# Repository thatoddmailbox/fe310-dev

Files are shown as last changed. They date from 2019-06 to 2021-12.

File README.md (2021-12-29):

# fe310-dev

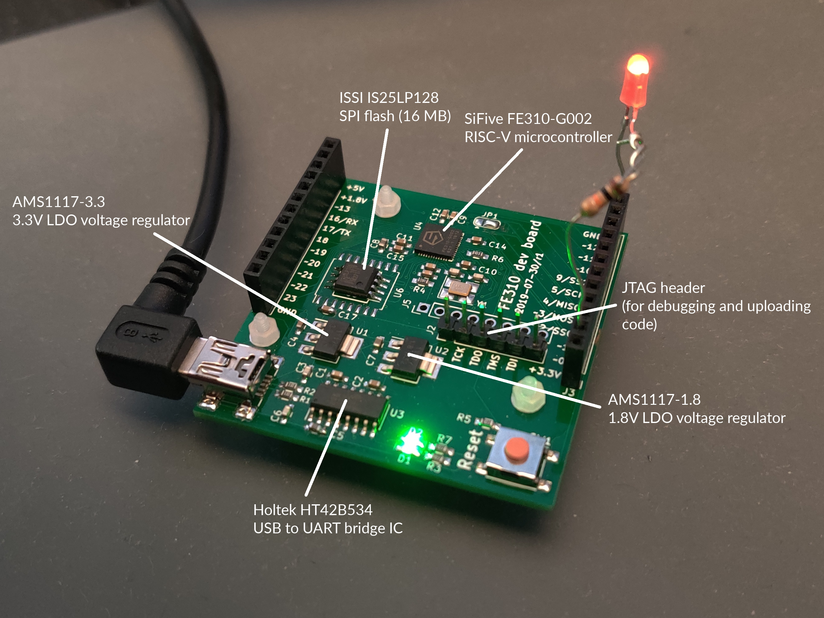
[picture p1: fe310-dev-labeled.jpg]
An image of the board


A development board for the [SiFive FE310](https://sifive.cdn.prismic.io/sifive/4999db8a-432f-45e4-bab2-57007eed0a43_fe310-g002-datasheet-v1p2.pdf), a RISC-V microcontroller. Compatible with both the FE310-G000 and FE310-G002.

## Revisions
* Revision 0 - initial revision
	* [revision 0 schematic](./mfg/rev0/fe310-dev.pdf), [revision 0 gerbers](./mfg/rev0), [revision 0 known issues](https://github.com/thatoddmailbox/fe310-dev/issues?q=is%3Aissue+label%3A%22affects+rev+0%22+) 
* Revision 1 - added support for the G002, added mounting holes, fixed silkscreen labels for pins and LEDs
	* [revision 1 schematic](./mfg/rev1/fe310-dev.pdf), [revision 1 gerbers](./mfg/rev1), [revision 1 known issues](https://github.com/thatoddmailbox/fe310-dev/issues?q=is%3Aissue+label%3A%22affects+rev+1%22+)

## Pinouts
The main pins are on the sides, and are labeled on the silkscreen. PWM capable pins are labeled with a ~, and pins with support for the SPI or UART peripherals have their functions labeled.

In the middle of the board, there are two sets of pins. The first is the JTAG header, which is partially labeled. When holding the board upright (so the "FE310 dev board" text can be read, and the USB port faces upwards), the pins are as follows:

* +3.3V
* TCK
* TDO
* TMS
* TDI
* GND

Most of these should go directly to the matching pin on your JTAG adapter. The one exception is +3.3V. If you want to power the board from your adapter, connect +3.3V to your adapter's power; however, if you want to power the board from USB (so that you can see the serial port), then leave the JTAG header's +3.3V pin disconnected.

The second set of pins has no labels. When holding the board upright, the pins are as follows:

* +1.8V
* AON_PMU_OUT_0
* AON_PMU_OUT_1
* AON_PMU_DWAKEUP_N
* AON_ERST_N
* AON_PSD_LFALTCLK
* AON_PSD_LFALTSEL
* GND

These are part of the Always-On (AON) Block of the FE310. You can check the FE310 manual for more information about these pins; however, in most cases, the only relevant pin is AON_ERST_N, which resets the chip (and is connected to the Reset button on the board). **Note that just because there's a +1.8V pin does _not_ mean the AON pins operate at 1.8V. See [issue #7](https://github.com/thatoddmailbox/fe310-dev/issues/7) for details.**

## Helpful links
* [Forked freedom-e-sdk](https://github.com/thatoddmailbox/freedom-e-sdk)
* [Revision 1 Schematic](./mfg/rev1/fe310-dev.pdf)
* [FE310-G002 Datasheet v1p0](https://sifive.cdn.prismic.io/sifive%2F3d777659-a0dd-49ed-a011-5bebba17aecf_fe310-g002-ds.pdf)
* [FE310-G002 Manual v19p04](https://sifive.cdn.prismic.io/sifive%2F9ecbb623-7c7f-4acc-966f-9bb10ecdb62e_fe310-g002.pdf)

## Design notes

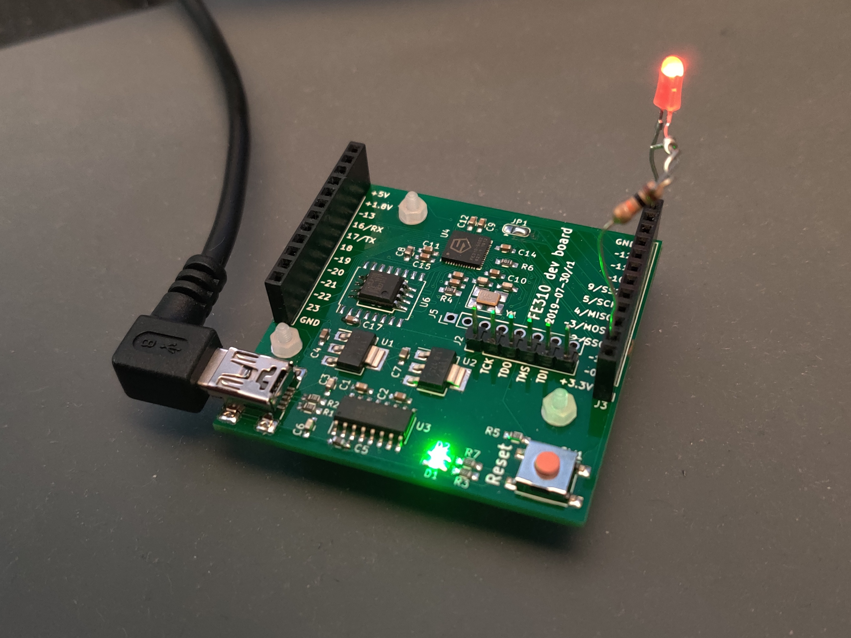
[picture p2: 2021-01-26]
fe310-dev.jpg

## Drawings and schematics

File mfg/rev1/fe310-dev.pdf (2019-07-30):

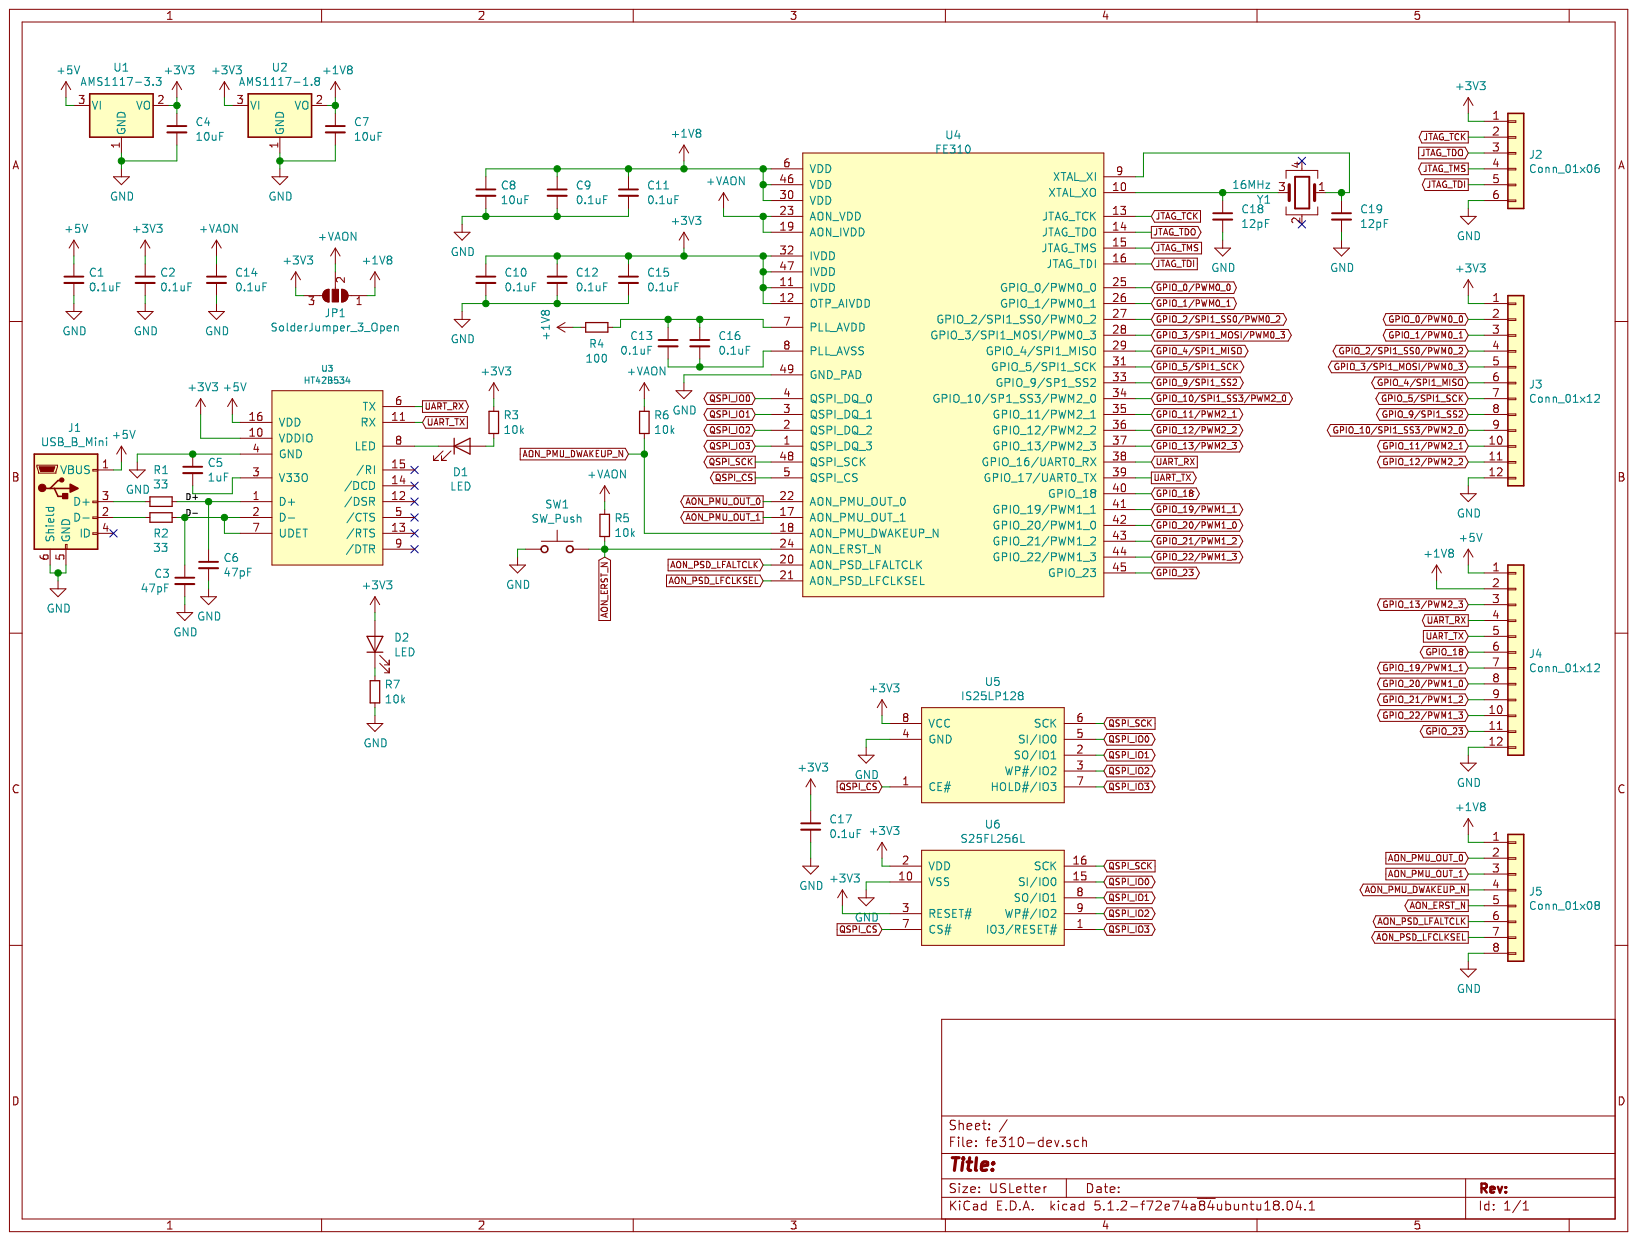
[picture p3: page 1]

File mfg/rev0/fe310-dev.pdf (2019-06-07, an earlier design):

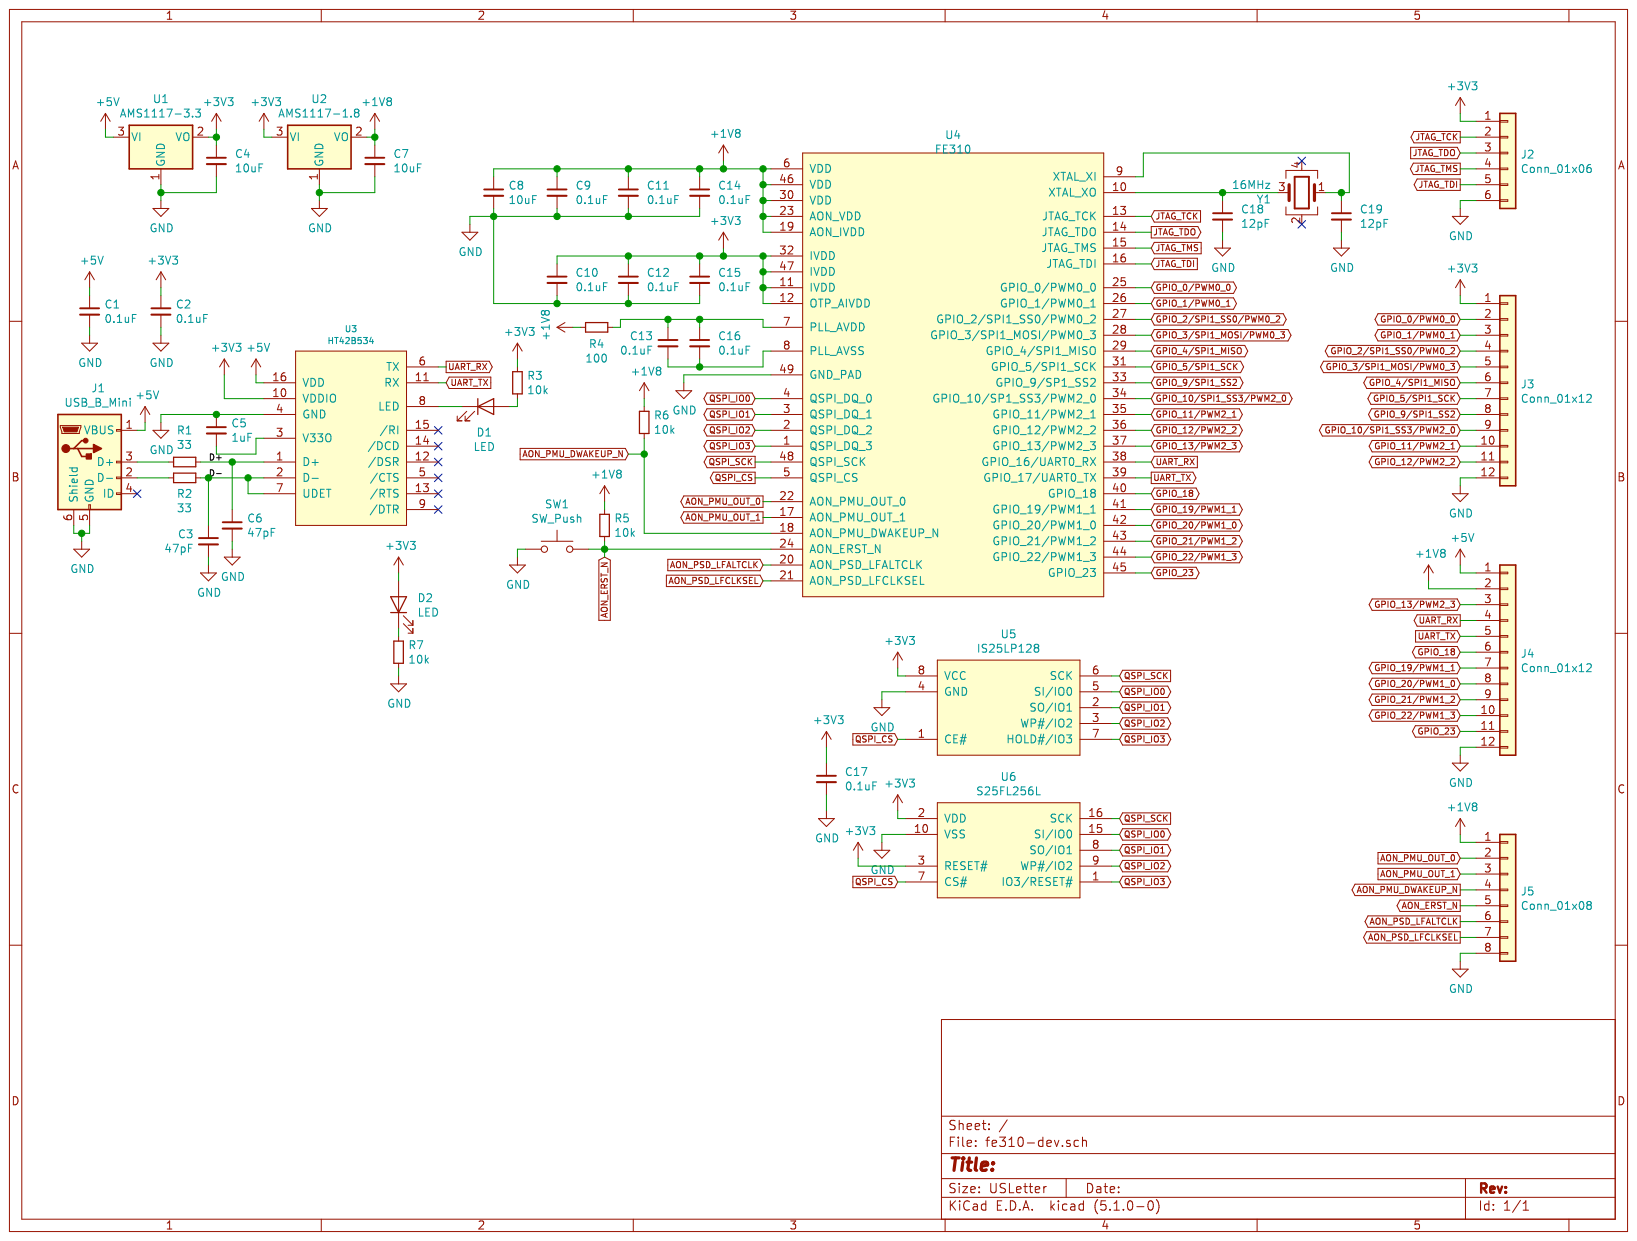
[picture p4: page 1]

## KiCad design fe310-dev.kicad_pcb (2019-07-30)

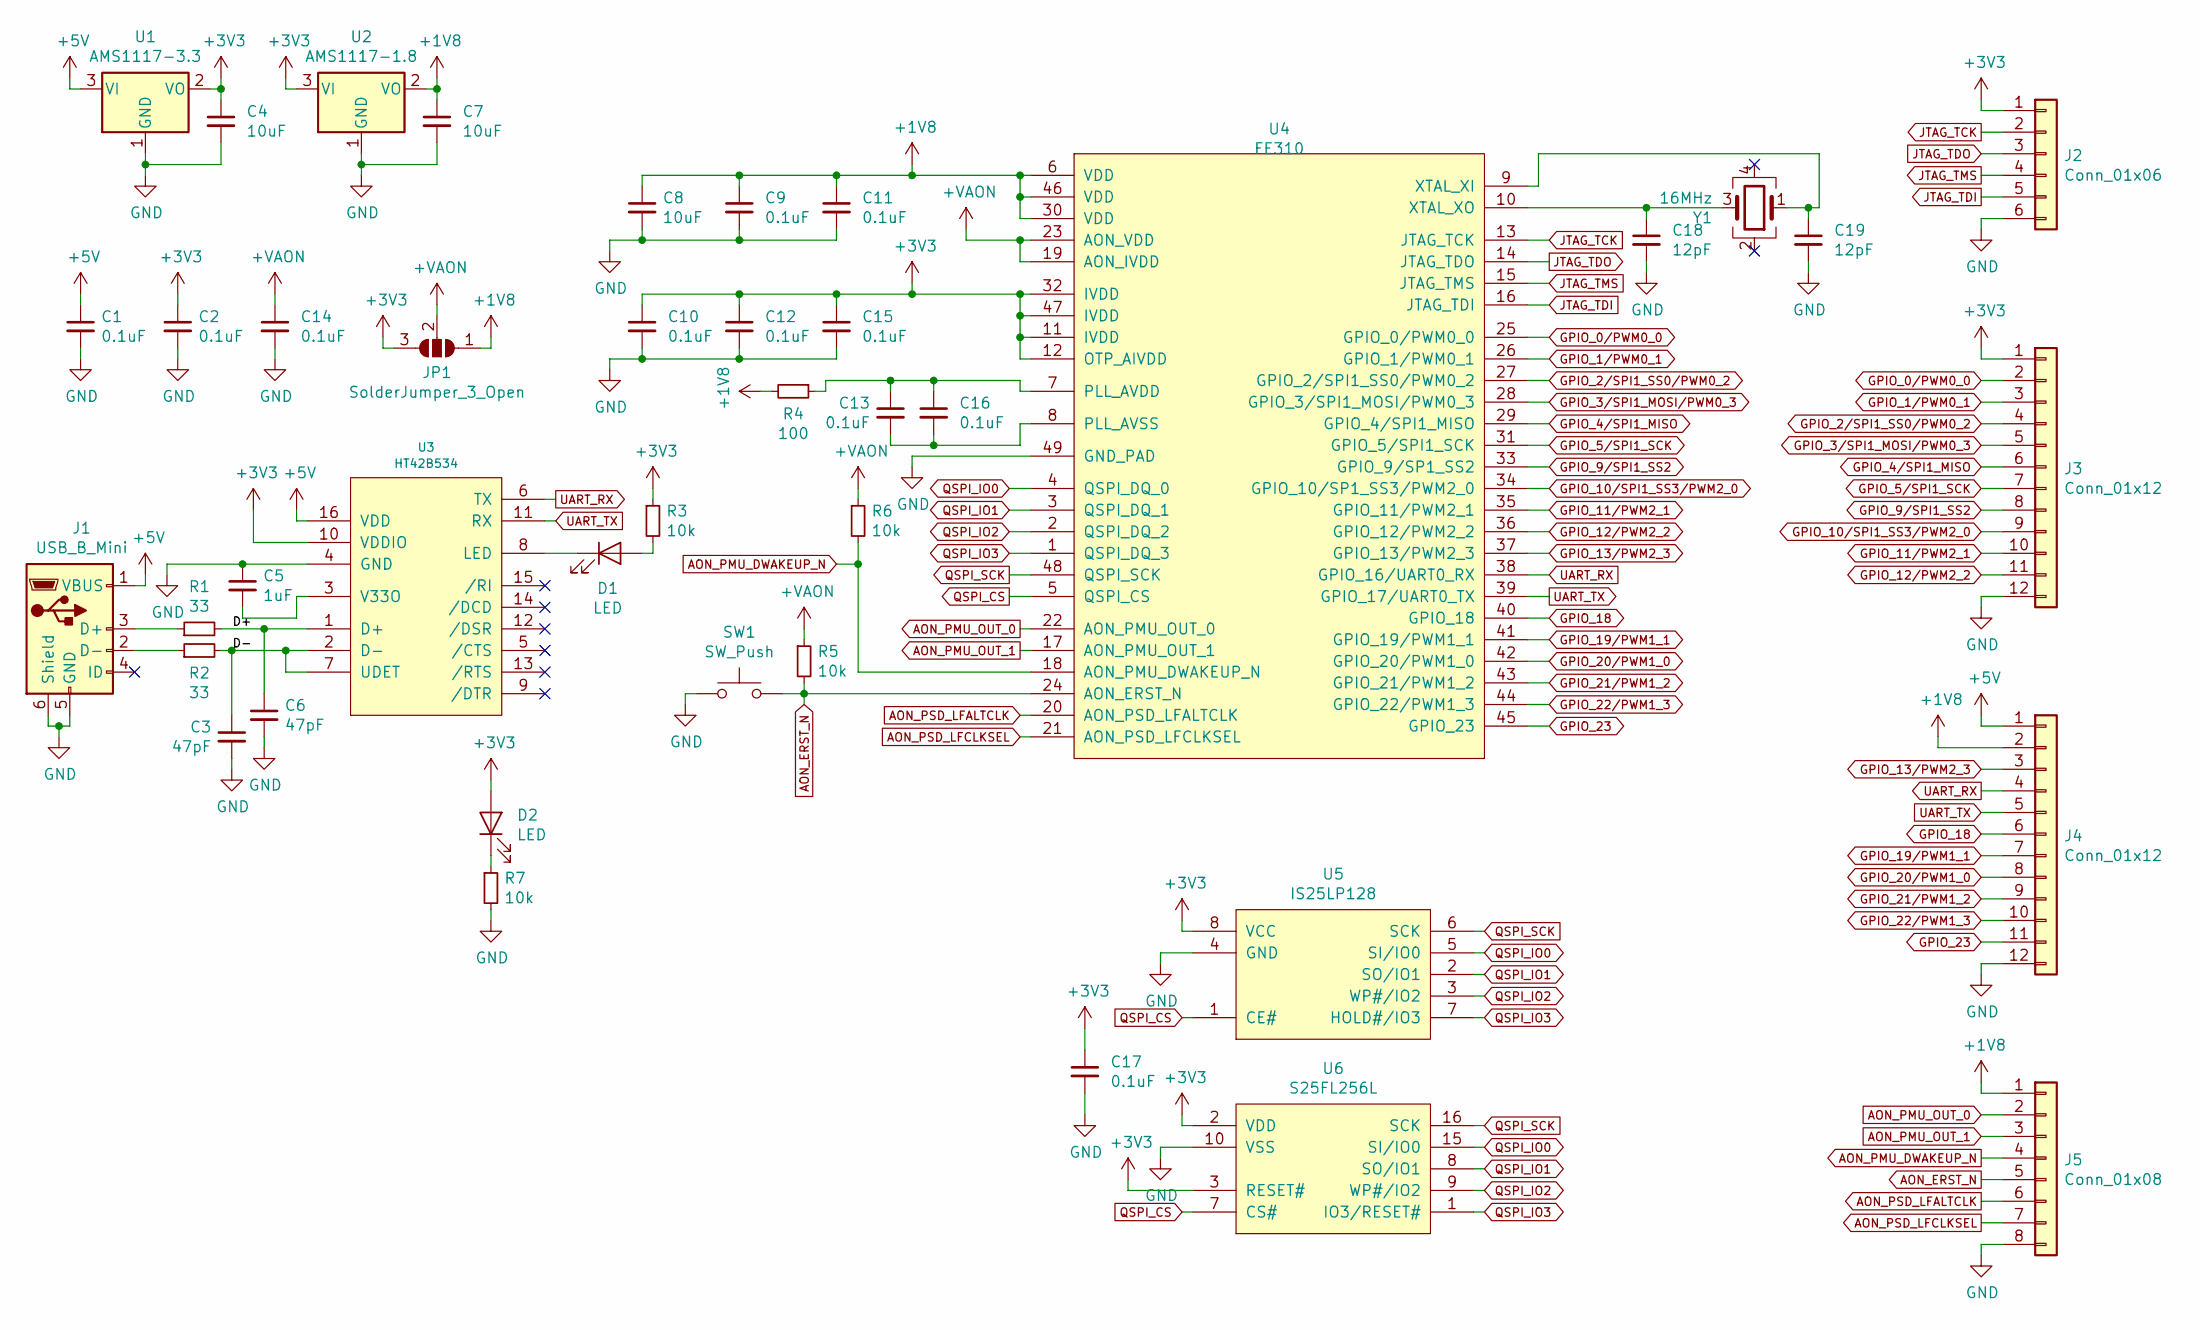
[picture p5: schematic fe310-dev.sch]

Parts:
C1, C2, C9, C10, C11, C12, C13, C14, C15, C16, C17: 0.1uF; C_0603_HandSoldering
C3, C6: 47pF; C_0603_HandSoldering
C4, C7, C8: 10uF; C_0603_HandSoldering
C5: 1uF; C_0603_HandSoldering
C18, C19: 12pF; C_0603_HandSoldering
D1, D2: LED; LED_0603_HandSoldering
J1: USB_B_Mini; USB_Mini-B
J2: Conn_01x06; Pin_Header_Straight_1x06_Pitch2.54mm
J3, J4: Conn_01x12; Pin_Header_Straight_1x12_Pitch2.54mm
J5: Conn_01x08; Pin_Header_Straight_1x08_Pitch2.54mm
JP1: SolderJumper_3_Open; SolderJumper-3_P1.3mm_Open_RoundedPad1.0x1.5mm
R1, R2: 33; R_0603_HandSoldering
R3, R5, R6, R7: 10k; R_0603_HandSoldering
R4: 100; R_0603_HandSoldering
SW1: SW_Push; SW_SPST_PTS645
U1: AMS1117-3.3; SOT-223-3_TabPin2
U2: AMS1117-1.8; SOT-223-3_TabPin2
U3: HT42B534; SOIC-16_3.9x9.9mm_Pitch1.27mm
U4: FE310; QFN-48-1EP_6x6mm_Pitch0.4mm_ThermalVias
U5: IS25LP128; SO-8_5.3x6.2mm_Pitch1.27mm
U6: S25FL256L; SOIC-16W_7.5x10.3mm_Pitch1.27mm
Y1: 16MHz; Crystal_SMD_3225-4pin_3.2x2.5mm_HandSoldering

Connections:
+1V8: C7.1, C8.1, C9.1, C11.1, J4.2, J5.1, JP1.1 (A), R4.2, U2.2 (VO), U4.6 (VDD), U4.30 (VDD), U4.46 (VDD)
+3V3: C2.1, C4.1, C10.1, C12.1, C15.1, C17.1, D2.2 (A), J2.1, J3.1, JP1.3 (B), R3.1, U1.2 (VO), U2.3 (VI), U3.10 (VDDIO), U4.11 (IVDD), U4.12 (OTP_AIVDD), U4.32 (IVDD), U4.47 (IVDD), U5.8 (VCC), U6.2 (VDD), U6.3 (RESET#)
+5V: C1.1, J1.1 (VBUS), J4.1, U1.3 (VI), U3.16 (VDD)
+VAON: C14.1, JP1.2 (C), R5.1, R6.1, U4.19 (AON_IVDD), U4.23 (AON_VDD)
/D+: C6.1, R1.2, U3.1 (D+)
/D-: C3.1, R2.2, U3.2 (D-), U3.7 (UDET)
AON_ERST_N: J5.5, R5.2, SW1.2, U4.24 (AON_ERST_N)
AON_PMU_DWAKEUP_N: J5.4, R6.2, U4.18 (AON_PMU_DWAKEUP_N)
AON_PMU_OUT_0: J5.2, U4.22 (AON_PMU_OUT_0)
AON_PMU_OUT_1: J5.3, U4.17 (AON_PMU_OUT_1)
AON_PSD_LFALTCLK: J5.6, U4.20 (AON_PSD_LFALTCLK)
AON_PSD_LFCLKSEL: J5.7, U4.21 (AON_PSD_LFCLKSEL)
GND: C1.2, C2.2, C3.2, C4.2, C5.1, C6.2, C7.2, C8.2, C9.2, C10.2, C11.2, C12.2, C14.2, C15.2, C17.2, C18.2, C19.2, J1.5 (GND), J1.6 (Shield), J2.6, J3.12, J4.12, J5.8, R7.2, SW1.1, U1.1 (GND), U2.1 (GND), U3.4 (GND), U4.49 (GND_PAD), U5.4 (GND), U6.10 (VSS)
GPIO_0/PWM0_0: J3.2, U4.25 (GPIO_0/PWM0_0)
GPIO_1/PWM0_1: J3.3, U4.26 (GPIO_1/PWM0_1)
GPIO_2/SPI1_SS0/PWM0_2: J3.4, U4.27 (GPIO_2/SPI1_SS0/PWM0_2)
GPIO_3/SPI1_MOSI/PWM0_3: J3.5, U4.28 (GPIO_3/SPI1_MOSI/PWM0_3)
GPIO_4/SPI1_MISO: J3.6, U4.29 (GPIO_4/SPI1_MISO)
GPIO_5/SPI1_SCK: J3.7, U4.31 (GPIO_5/SPI1_SCK)
GPIO_9/SPI1_SS2: J3.8, U4.33 (GPIO_9/SP1_SS2)
GPIO_10/SPI1_SS3/PWM2_0: J3.9, U4.34 (GPIO_10/SP1_SS3/PWM2_0)
GPIO_11/PWM2_1: J3.10, U4.35 (GPIO_11/PWM2_1)
GPIO_12/PWM2_2: J3.11, U4.36 (GPIO_12/PWM2_2)
GPIO_13/PWM2_3: J4.3, U4.37 (GPIO_13/PWM2_3)
GPIO_18: J4.6, U4.40 (GPIO_18)
GPIO_19/PWM1_1: J4.7, U4.41 (GPIO_19/PWM1_1)
GPIO_20/PWM1_0: J4.8, U4.42 (GPIO_20/PWM1_0)
GPIO_21/PWM1_2: J4.9, U4.43 (GPIO_21/PWM1_2)
GPIO_22/PWM1_3: J4.10, U4.44 (GPIO_22/PWM1_3)
GPIO_23: J4.11, U4.45 (GPIO_23)
JTAG_TCK: J2.2, U4.13 (JTAG_TCK)
JTAG_TDI: J2.5, U4.16 (JTAG_TDI)
JTAG_TDO: J2.3, U4.14 (JTAG_TDO)
JTAG_TMS: J2.4, U4.15 (JTAG_TMS)
unnamed: C5.2, U3.3 (V33O)
unnamed: C13.1, C16.1, R4.1, U4.7 (PLL_AVDD)
unnamed: C13.2, C16.2, U4.8 (PLL_AVSS)
unnamed: C18.1, U4.10 (XTAL_XO), Y1.3
unnamed: C19.1, U4.9 (XTAL_XI), Y1.1
unnamed: D1.1 (K), U3.8 (LED)
unnamed: D1.2 (A), R3.2
unnamed: D2.1 (K), R7.1
unnamed: J1.2 (D-), R2.1
unnamed: J1.3 (D+), R1.1
QSPI_CS: U4.5 (QSPI_CS), U5.1 (CE#), U6.7 (CS#)
QSPI_IO0: U4.4 (QSPI_DQ_0), U5.5 (SI/IO0), U6.15 (SI/IO0)
QSPI_IO1: U4.3 (QSPI_DQ_1), U5.2 (SO/IO1), U6.8 (SO/IO1)
QSPI_IO2: U4.2 (QSPI_DQ_2), U5.3 (WP#/IO2), U6.9 (WP#/IO2)
QSPI_IO3: U4.1 (QSPI_DQ_3), U5.7 (HOLD#/IO3), U6.1 (IO3/RESET#)
QSPI_SCK: U4.48 (QSPI_SCK), U5.6 (SCK), U6.16 (SCK)
UART_RX: J4.4, U3.6 (TX), U4.38 (GPIO_16/UART0_RX)
UART_TX: J4.5, U3.11 (RX), U4.39 (GPIO_17/UART0_TX)

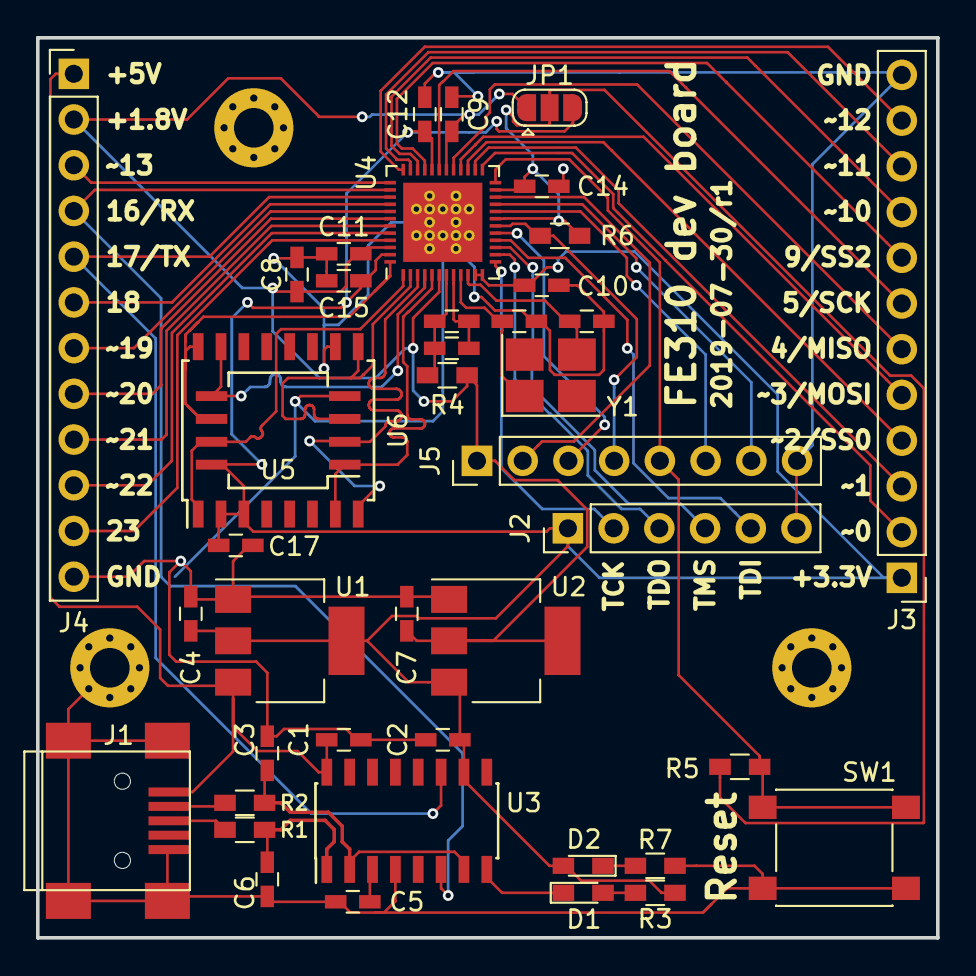
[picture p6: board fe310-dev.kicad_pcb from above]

Board: 2 copper layers, 50.0 x 50.0 mm, 42 parts (0 on the bottom side), 52 nets.

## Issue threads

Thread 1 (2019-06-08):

Silkscreen labels for GPIO are just wrong

thatoddmailbox, 2019-06-08:
Somehow the labels on the board were flipped from the actual pin headers, meaning that all of the IO pin labels are completely incorrect...

Closed 2019-07-05.

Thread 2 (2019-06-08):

Labels for LEDs are flipped

thatoddmailbox, 2019-06-08:
The D1 and D2 labels for the LEDs are flipped (that is, the LED marked D1 is actually D2, and vice versa)

Closed 2019-07-05.

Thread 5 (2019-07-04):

Support FE310-G002

thatoddmailbox, 2019-07-04:
The G000 and G002 have the same pins in the same places, but it looks like the G002 requires 3.3v on the AON lines while the G000 wanted 1.8v. This can be fixed with a jumper to allow setting the AON domain's voltage. Apart from that, there doesn't seem to be any major differences in required circuitry/power/etc...

Closed 2021-01-24.

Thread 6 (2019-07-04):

Symbols should follow KLC

thatoddmailbox, 2019-07-04:
The custom symbols should probably follow KLC (location of power pins seems to be the main issue) so that they could eventually be contributed back to the main KiCad library repo.

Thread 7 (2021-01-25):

AON header should have +VAON, not +1.8V

thatoddmailbox, 2021-01-25:
Currently, the AON header's first pin goes to +1.8V. This made sense for the FE310-G000, but on the G002, the AON power domain voltage was changed to +3.3V. While the rest of the board was changed to allow a selectable AON voltage via J1, it looks like I left this fixed at +1.8V.

This isn't a major issue, it's just confusing if you're using the G002.

thatoddmailbox, 2021-01-25:
Unfortunately, the AON pin header is in the path that the FE310 gets its main +1.8V power source from, which makes this annoying to bodge. You would most likely have to cut both traces going to J5 and run a bodge wire from U2 to R4. Then you could run another wire (under the board?) from +3.3V (which is conveniently available from J2) to J5.

Alternatively (and more correctly), you could run that second wire from J5 to R5, which would give you the AON voltage as selected by JP1. However, since you'd only have to do this modification on a board with a G002, in which case you'd know +3.3V is the AON voltage, I'm not sure that it makes a huge difference.

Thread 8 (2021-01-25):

UART1 and I2C0 pins should be labeled

thatoddmailbox, 2021-01-25:
It's incredibly minor, but the new G002 peripherals (UART1 and I2C0) were never labeled on the silkscreen.

See page 78 of the FE310-G002 manual, and page 3 of the FE310-G002 datasheet.

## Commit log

2019-06-07 commit rev 0 schematic, pcb, and gerbers
    [fe310-dev-B.Cu.gbr, fe310-dev-B.Mask.gbr, fe310-dev-B.Paste.gbr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]
2019-07-04 add jumper for selectable AON power domain voltage, which should work for #5
    [fe310-dev.kicad_pcb, fe310-dev.sch]
2019-07-04 pullup for AON_ERST_N should be connected to the AON i/o voltage
    [fe310-dev.kicad_pcb, fe310-dev.sch]
2019-07-04 same for AON wakeup pin...
    [fe310-dev.kicad_pcb, fe310-dev.sch]
2019-07-05 various fixes and updates to silkscreen, closes #1 and #2
    [fe310-dev.kicad_pcb]
2019-07-05 add m2 mounting holes and reroute traces to accommodate (closes #3)
    [fe310-dev.kicad_pcb]
2019-07-30 update date on pcb because i'm lazy and took 3 weeks before sending the board to be fabbed
    [fe310-dev.kicad_pcb]
2019-07-30 add gerbers for rev 1
    [fe310-dev-B_Cu.gbr, fe310-dev-B_Mask.gbr, fe310-dev-B_SilkS.gbr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]
2021-01-25 readme: add note about reset pin
2021-01-25 readme: add note about AON power domain
2021-01-25 readme: add link to rev1 schematic
2021-01-26 readme: add clearer links to schematic and gerbers
